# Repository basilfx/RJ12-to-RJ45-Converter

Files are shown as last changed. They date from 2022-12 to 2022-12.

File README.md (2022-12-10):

# RJ12-to-RJ45 Converter
A converter for RJ12 to RJ45 for just a very specific use case.

## Introduction
My charge point connects to my Dutch Smart Meter (DSMR), to dynamically adjust
the maximum allowed current. It utillizes the P1 port, which uses a port with a
RJ12 connector. Between the charger and the DSMR, I installed a Cat 5e cable.

Crimping an RJ12 connector onto a Cat 5e cable will not make a durable
connection. I therefore designed this converter and 3D printed an enclosure for
it, just because I can.

I installed a normal RJ45 connector on both ends of the cable, installed two
converters and installed short 'telephone cables' (with RJ11 connectors) to
connect the charge point to the convert, and the DSMR to the converter.

## Contents
* The `3d/` folder contains a 3D-printable design for an enclosure.
* The `pcb/` folder contains the Kicad schema and board design.

## License
The work in this repository is covered by CC BY-NC-SA 4.0. See the `LICENSE.md`
file for more information.

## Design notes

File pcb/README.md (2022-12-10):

# RJ12-to-RJ45 Converter

## Board
Top layer
Bottom layer

## Schema
You can find the schema [here](RJ12_RJ45.pdf).

## BoM
The (interactive) BoM can be found [here](https://basilfx.github.io/RJ12-to-RJ45-Converter/pcb/BoM/ibom.html).

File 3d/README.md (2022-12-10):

# RJ12-to-RJ45 Converter

## Pictures
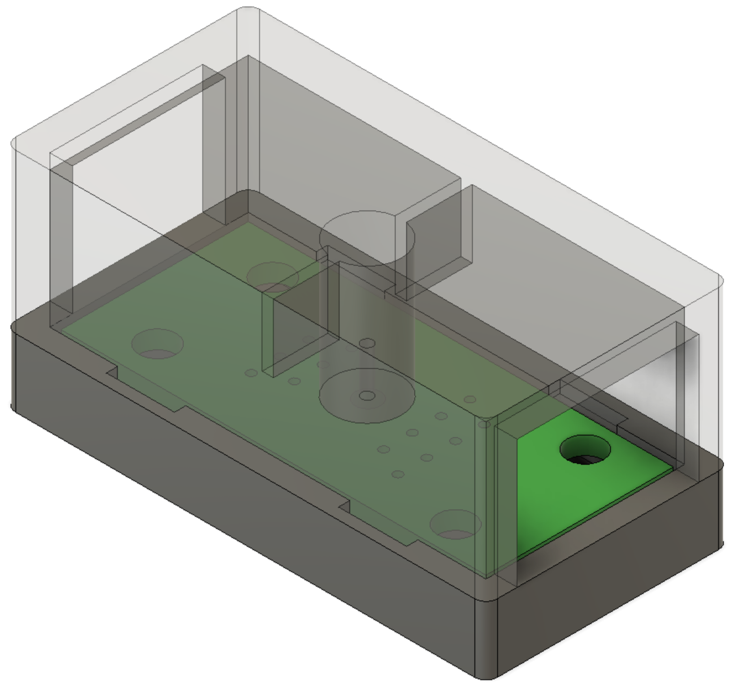
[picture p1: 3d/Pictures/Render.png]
3D render of the enclosure.
[](Pictures/Render.png)

## Dimensions
The enclosure measures approximately 41 x 22 x 20 mm.

## Print Settings
Print both parts in PETG at 0.2 mm layer height with 100% infill.

## Post processing
Clean-up both parts, and adjust the small 'tabs' with a file, so that both
halves fit. They can then be clamped together with a small M2 self-tapping
screw.

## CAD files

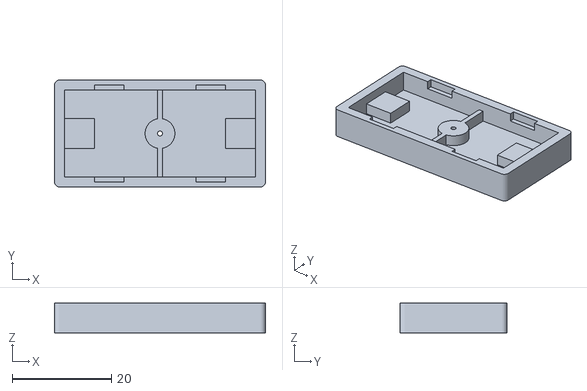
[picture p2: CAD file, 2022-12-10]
3d/Bottom.stl
42.5 x 21.5 x 6.00

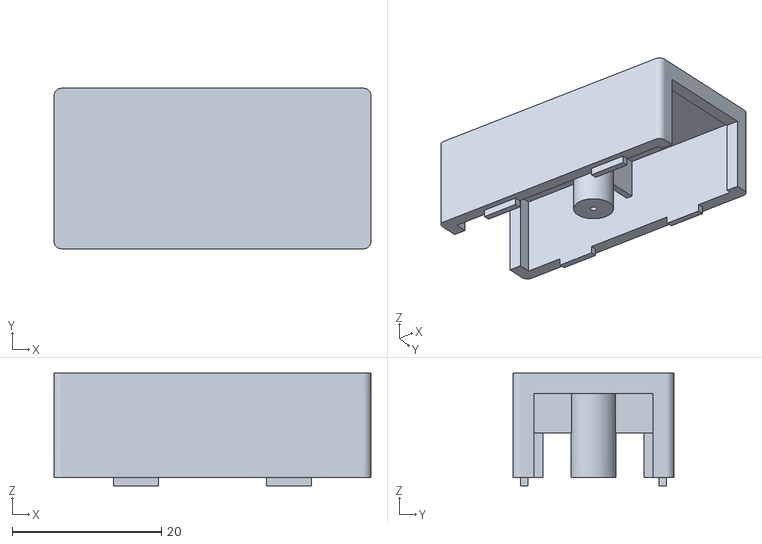
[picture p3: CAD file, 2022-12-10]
3d/Top.stl
42.5 x 21.5 x 15.1

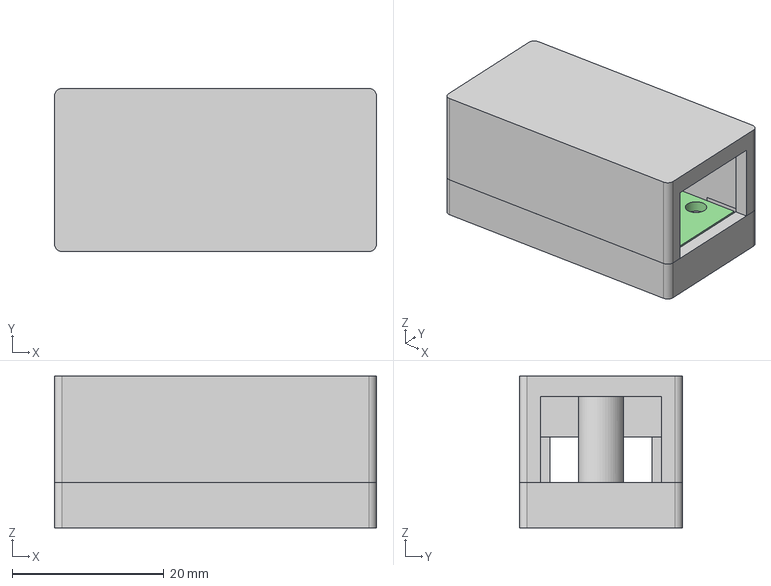
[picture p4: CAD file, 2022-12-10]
3d/Enclosure.step
42.5 x 21.5 x 20.0 mm

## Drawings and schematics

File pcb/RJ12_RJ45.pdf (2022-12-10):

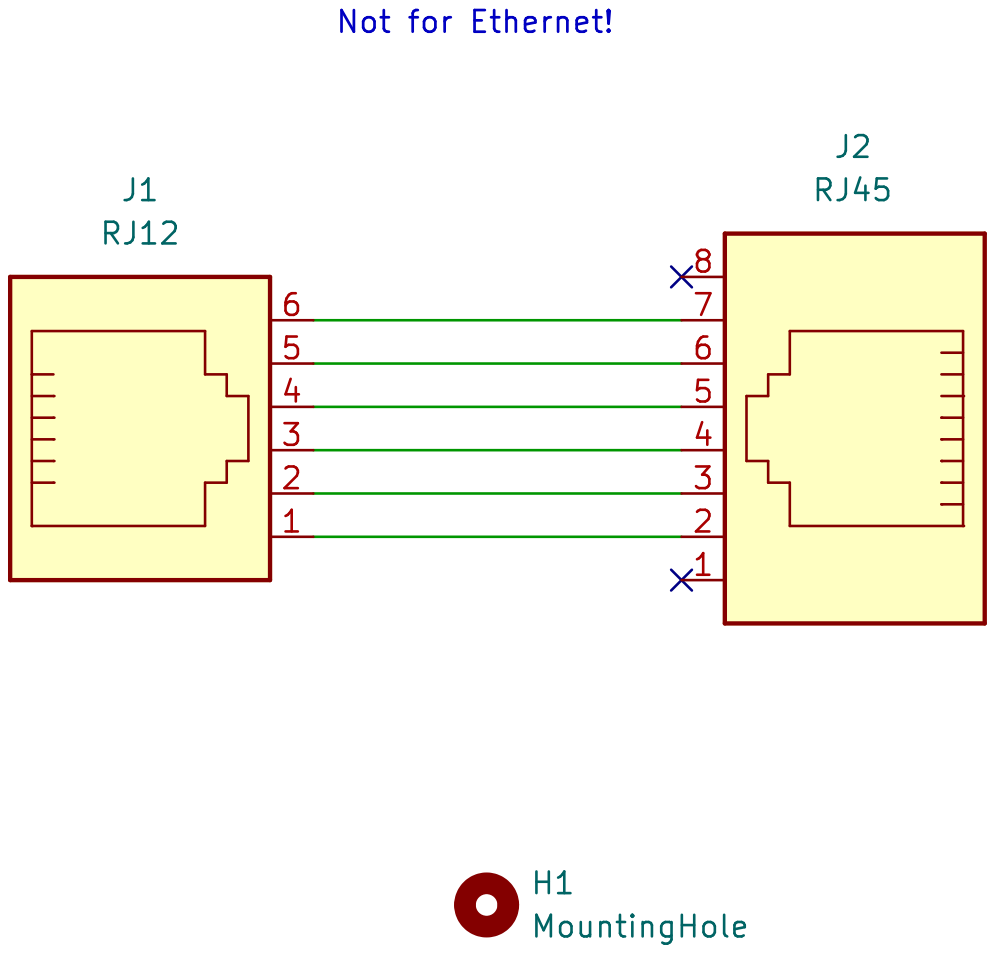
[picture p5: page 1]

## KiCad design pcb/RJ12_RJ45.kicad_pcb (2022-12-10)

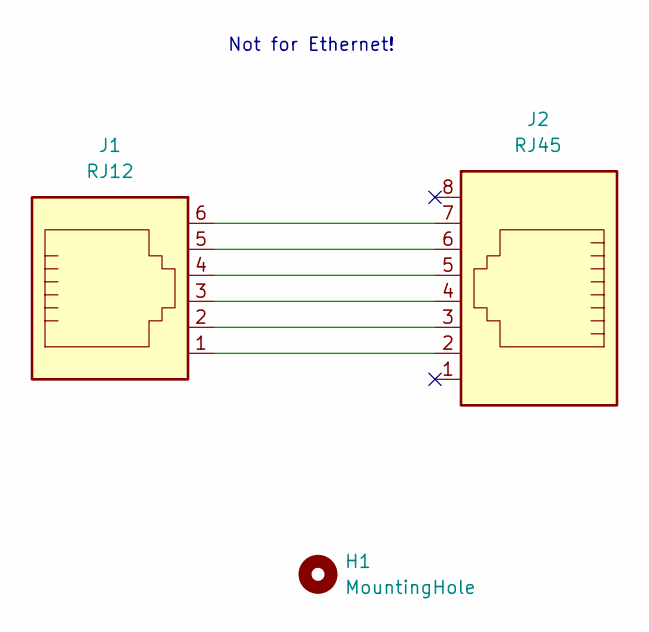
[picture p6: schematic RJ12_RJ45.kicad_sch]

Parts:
H1: MountingHole; MountingHole_2.2mm_M2
J1: RJ12; RJ12_Amphenol_54601
J2: RJ45; RJ45_Amphenol_54602-x08_Horizontal

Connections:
unnamed: J1.1, J2.2
unnamed: J1.2, J2.3
unnamed: J1.3, J2.4
unnamed: J1.4, J2.5
unnamed: J1.5, J2.6
unnamed: J1.6, J2.7

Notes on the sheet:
Not for Ethernet!

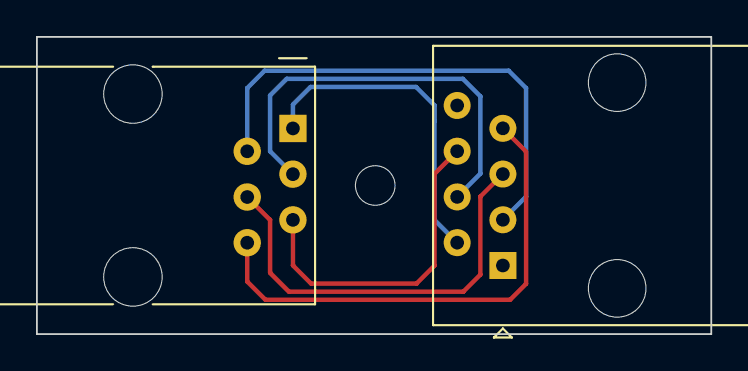
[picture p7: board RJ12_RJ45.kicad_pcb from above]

Board: 2 copper layers, 37.5 x 16.5 mm, 3 parts (0 on the bottom side), 6 nets.

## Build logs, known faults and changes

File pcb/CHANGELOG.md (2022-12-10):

# Changelog

## v1.0.0
Released 11 December 2022

Highlights:
* Initial version.

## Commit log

2022-12-10 Initial import of project
    [Bottom.stl, Enclosure.step, RJ45_RJ12.kicad_pcb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]
2022-12-10 Fix name of files to fix links
    [RJ12_RJ45.kicad_pcb, RJ12_RJ45.kicad_sch]
